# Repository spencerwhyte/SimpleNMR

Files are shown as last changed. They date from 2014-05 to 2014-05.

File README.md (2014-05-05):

Simple NMR
==============
This is my first adventure into NMR and I want to keep everything as simple as possible for the first design. 

The process goes a little something like this.

1. Apply a pre-polarizing pulse to the sample.
2. Transmit 90 degree pulse
3. Listen to the FID

Transmit/Receive Board
----------

There is a board which controls the polarization, transmission amplification, and receiver amplification. kicad designs for this board can be found in the RelayBoard folder.

To elaborate on the simple process described above, here is what actually happens.

1. Apply a pre-polarizing pulse to the sample
	- Configure the relays to disable transmit and receive functionality (To protect the electronics)
	- Turn on the polarization coil
	- Wait some fixed period of time
	- Turn off the polarization coil 

2. Transmit 90 degree pulse
	- Configure the relays to allow transmission
	- Tell GNURadio to output a sine wave at the larmour frequency to the sound card/audio interface
	- Wait 90 degrees worth of time
	- Tell GNURadio to stop the output
	- Configure the relays to disable transmission

3. Listen to the FID
	- Configure the relays to enable receiving
	- Tell GNURadio to record from line-in 
	- Apply a Peak hold FFT to the input signal to see what we received

Amplification Board
------------

There is another board which amplifies the transmitted and received signals. kicad designs for the amplifier board can be found in the AmplifierBoard folder.

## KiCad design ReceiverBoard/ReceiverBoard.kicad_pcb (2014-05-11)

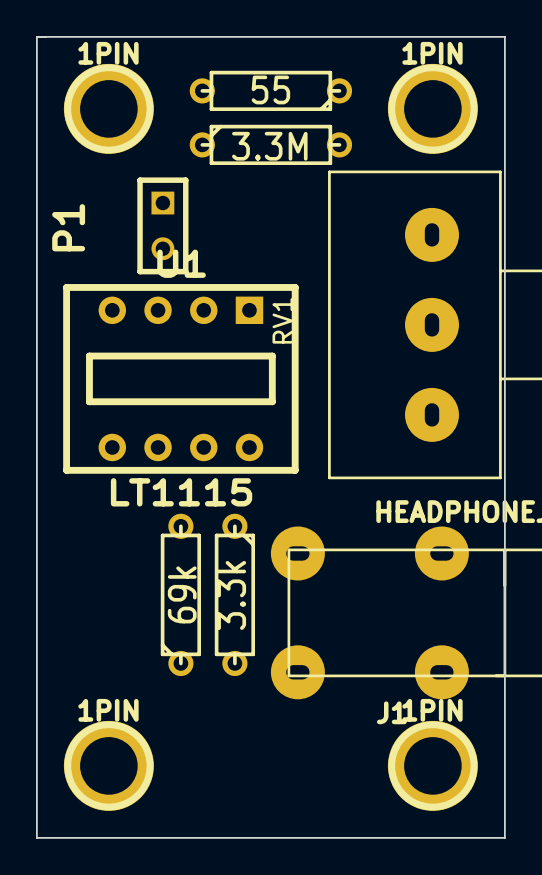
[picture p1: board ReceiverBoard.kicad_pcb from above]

Board: 2 copper layers, 26.0 x 44.5 mm, 12 parts (0 on the bottom side), 6 nets, no tracks yet.

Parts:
1PIN, 1PIN#2, 1PIN#3, 1PIN#4: P***; 1pin
J1: HEADPHONEJACK; HeadphoneJack
P1: CONN_2; PinHeader2
R1: 3.3M; R3
R2: 55; R3
R3: 69k; R3
R4: 3.3k; R3
RV1: POT; POT_P160KN
U1: LT1115; SWDIP4

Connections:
GND: J1.1, P1.1, R2.2, R4.1
unnamed: R1.2, R2.1, RV1.1
unnamed: R3.2, RV1.2, U1.6
unnamed: J1.2, R3.1, R4.2
unnamed: R1.1, U1.2
unnamed: P1.2, U1.3

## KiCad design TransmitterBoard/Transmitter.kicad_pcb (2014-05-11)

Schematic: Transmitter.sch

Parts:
J1: JACK_STEREO
K1: CONN_3
P1: CONN_2
R1: Rin
R2: Rf
RV1: 10k
U1: LF411

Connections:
GND: J1.1, K1.2 (PM), P1.2 (PM), R1.1
unnamed: R1.2, R2.2, U1.2 (-)
unnamed: J1.2, U1.3 (+)
unnamed: P1.1, RV1.2, U1.6
unnamed: R2.1, RV1.1
VCC: K1.1, U1.7 (v+)
VEE: K1.3, U1.4 (V-)

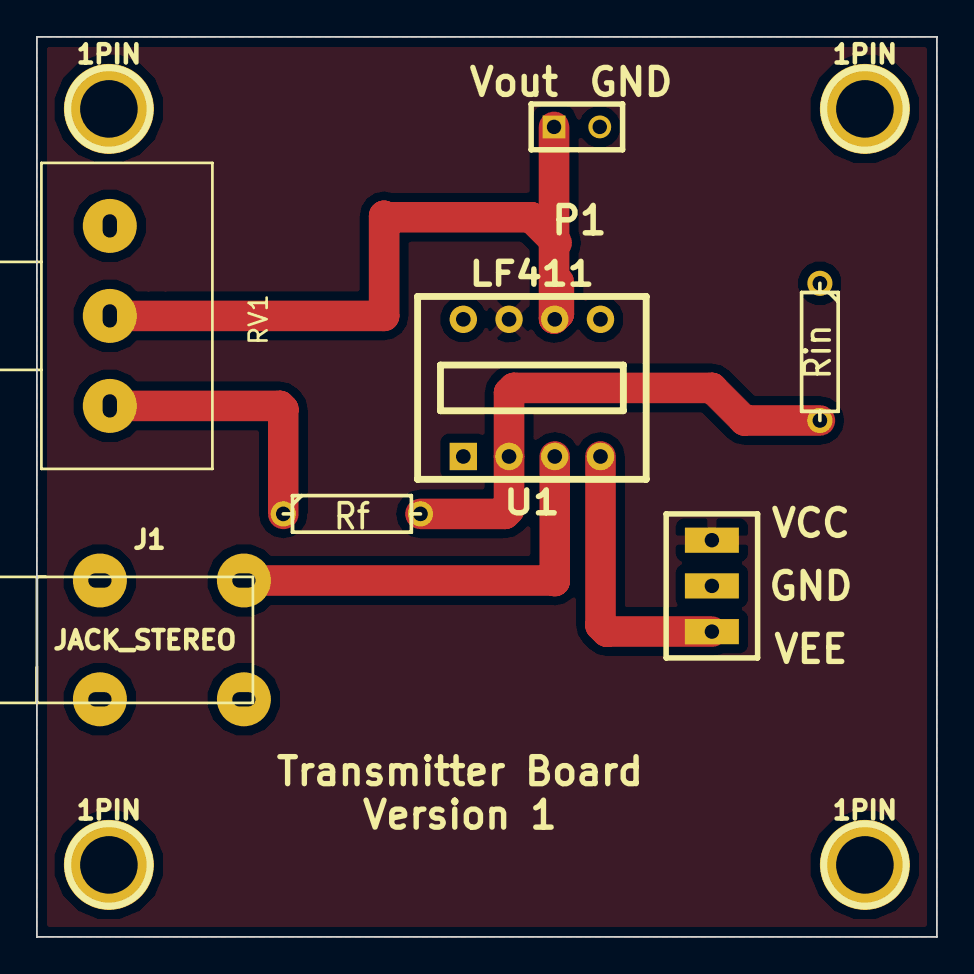
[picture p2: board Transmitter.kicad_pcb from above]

Board: 2 copper layers, 50.0 x 50.0 mm, 11 parts (0 on the bottom side), 7 nets.

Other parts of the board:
1PIN, 1PIN#2, 1PIN#3, 1PIN#4: P***; 1pin

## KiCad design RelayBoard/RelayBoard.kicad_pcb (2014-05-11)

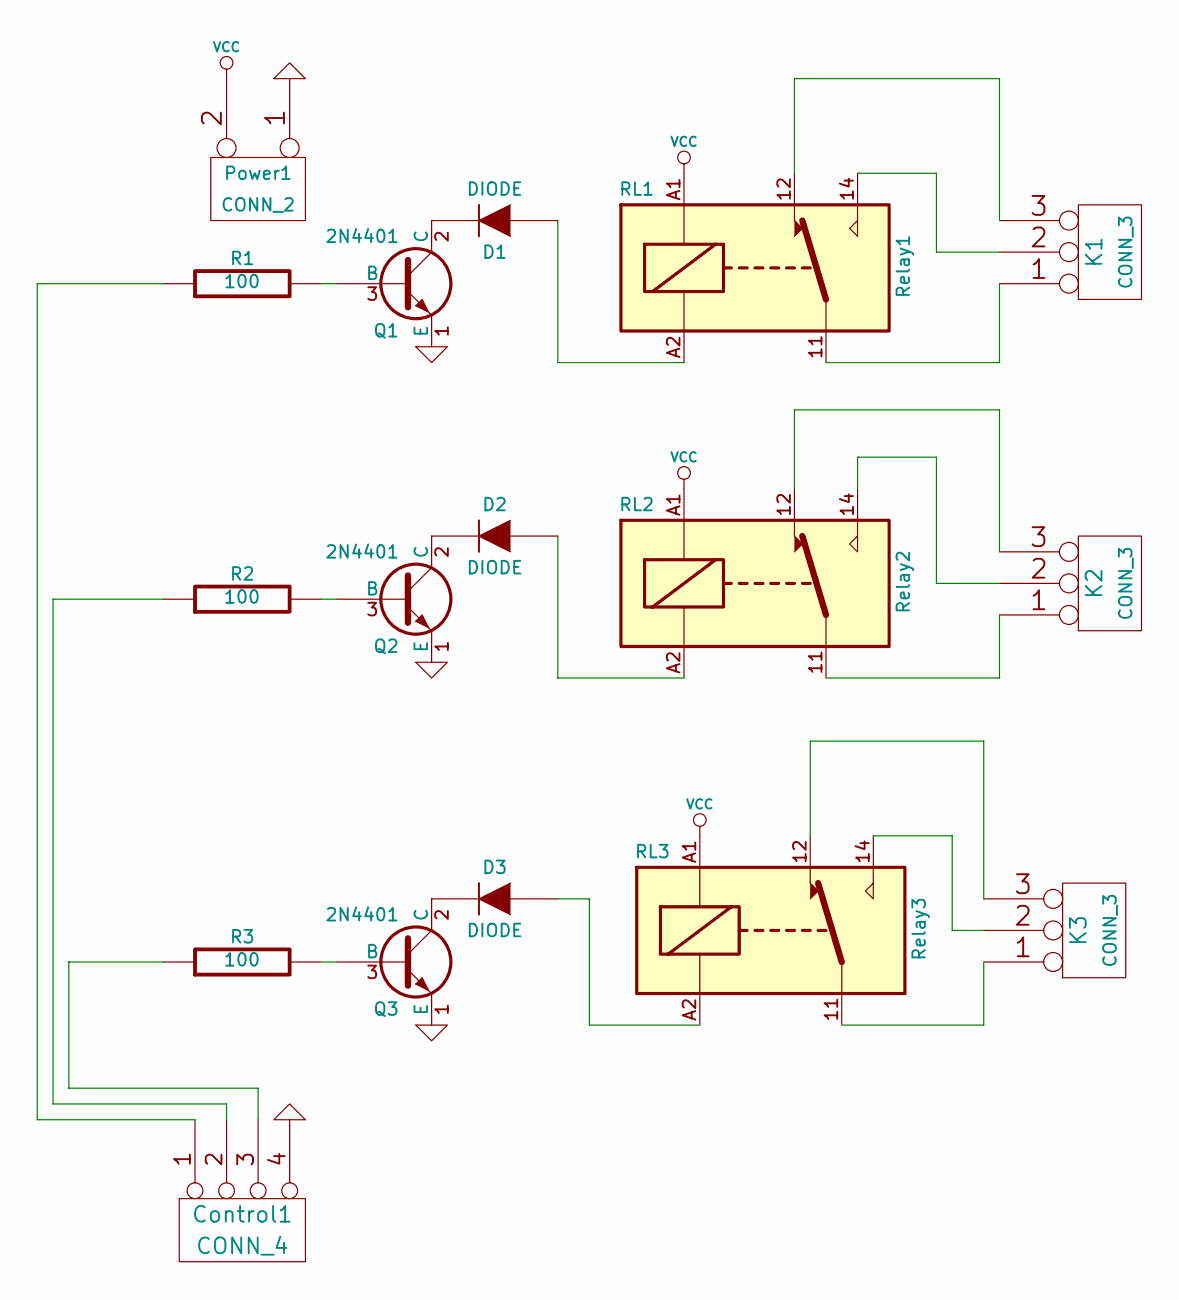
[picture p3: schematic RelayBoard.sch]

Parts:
Control1: CONN_4
D1, D2, D3: DIODE
K1, K2, K3: CONN_3
Power1: CONN_2
Q1, Q2, Q3: 2N4401
R1, R2, R3: 100
RL1: Relay1
RL2: Relay2
RL3: Relay3

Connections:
GND: Control1.4, Power1.1, Q1.1 (E), Q2.1 (E), Q3.1 (E)
unnamed: K2.3, RL2.12
unnamed: K2.1, RL2.11
unnamed: K3.3, RL3.12
unnamed: K3.2 (PM), RL3.14
unnamed: K3.1, RL3.11
unnamed: K2.2 (PM), RL2.14
unnamed: K1.2 (PM), RL1.14
unnamed: K1.3, RL1.12
unnamed: K1.1, RL1.11
unnamed: D3.2 (K), Q3.2 (C)
unnamed: D2.2 (K), Q2.2 (C)
unnamed: D1.2 (K), Q1.2 (C)
unnamed: Q3.3 (B), R3.2
unnamed: Control1.3, R3.1
unnamed: Q2.3 (B), R2.2
unnamed: Q1.3 (B), R1.2
unnamed: Control1.1, R1.1
unnamed: D3.1 (A), RL3.A2
unnamed: D2.1 (A), RL2.A2
unnamed: D1.1 (A), RL1.A2
unnamed: Control1.2, R2.1
VCC: Power1.2 (PM), RL1.A1, RL2.A1, RL3.A1

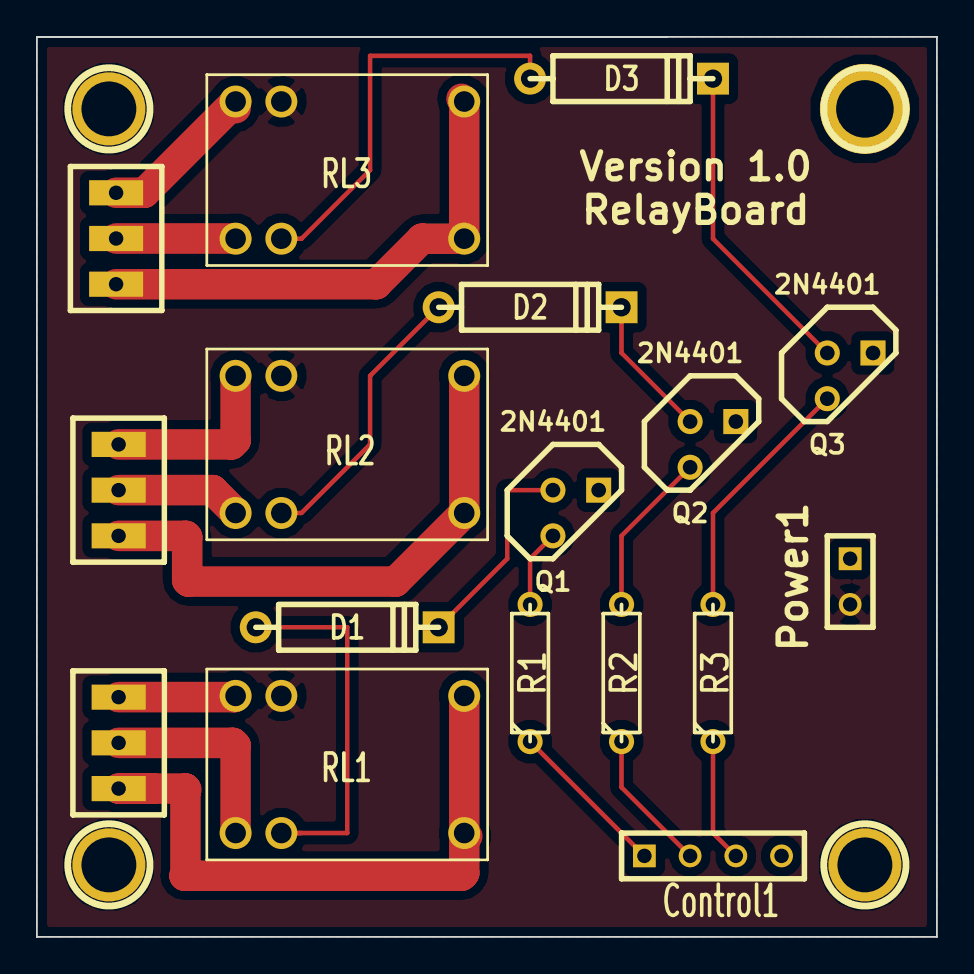
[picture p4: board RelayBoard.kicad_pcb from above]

Board: 2 copper layers, 50.0 x 50.0 mm, 21 parts (0 on the bottom side), 23 nets.

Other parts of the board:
1PIN, 1PIN#2, 1PIN#3, 1PIN#4: P***; 1pin

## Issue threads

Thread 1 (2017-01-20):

Would this work directly with a SDR?

lostinblue, 2017-01-20:
Could I just use this directly with an SDR like hackerRF?

spencerwhyte, 2017-01-31:
The short answer is not easily.

The long answer is, yes, and I want to try it someday! The cutoff frequency of the HackRF is about 10 MHz. Lets say you give yourself 1 MHz of bandwidth (that is an outrageous amount of bandwidth). You would need to get the hydrogen atoms talking at 11 MHz.

The Gyromagnetic ratio of hydrogen is 42.58 Mhz / Tesla.

B = 11 Mhz / (42.58 MHz / Tesla) = 0.25833 Tesla

Therefore you would need to have a homogeneous 0.258 T field on your sample, which isn't easy / cheap (unless you go for a smaller sample size).

kziblk, 2017-02-02:
I have one and I'm trying it now, I'm more of a programmer than a physicist though, I just think this would be awesome to have open source. I actually have two, I was planning on dedicated one to transmission and one to receiving.

If you have time to answer my stupid questions and help me make sense of it I could build on what you have here I would really appreciate it.

I have over 1 T field but I'm having trouble making sense of how exactly I should generate the Lam- frequency and how I should build the receiver coil.

kziblk, 2017-02-02:
Should I just be using RPITX + raspberry pi 3 to do the transmission? Seems like a much cheaper solution.

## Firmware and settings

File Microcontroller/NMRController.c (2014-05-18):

#include <msp430g2553.h>

/*
By: Spencer Whyte

This controls the polarization and transmit/receive coils by listening
for commands over a serial connection and controlling the relays.

This just turns the MSP430 into a cheap serial to parallel converter

*/

void enableUARTInterrupt(){
	IE2 |= UCA0RXIE; // Enable RX interrupt
}

void disableUARTInterrupt(){
	IE2 &= ~UCA0RXIE;
}


// Initializes the hardware used for the serial connection
// 9600 Baud
// 8N1
void initialize_uart(){
	BCSCTL1 = CALBC1_1MHZ; // Set DCO
	DCOCTL = CALDCO_1MHZ;
	P1SEL = BIT1 + BIT2 ; // P1.1 = Polarization, P1.2=T/R
	P1SEL2 = BIT1 + BIT2 ; // P1.1 = Polarization , P1.=T/R
	UCA0CTL1 |= UCSSEL_2; // SMCLK
	UCA0BR0 = 104; // 1MHz 9600
	UCA0BR1 = 0; // 1MHz 9600
	UCA0MCTL = UCBRS0; // Modulation
	UCA0CTL1 &= ~UCSWRST; // Initialize USCI state machine
}

void wait_for_button_press(){
	__bis_SR_register(LPM0_bits + GIE); // Enter low power mode and wait for the user to press the button
		
}

void initialize_leds(){
	P1DIR |= (BIT0|BIT4|BIT5); // Set the LEDs on P1.0, P1.6 as outputs
	P1OUT = 0; // Indicate that serial transfer is incomplete by displaying the yellow light
}

void main(void)
 
{
	WDTCTL = WDTPW + WDTHOLD; // Stop WDT

	initialize_leds(); // Initialize the LED's

	initialize_uart(); // Initialize the hardware for the serial connection
	
	enableUARTInterrupt();	

	__bis_SR_register(LPM0_bits + GIE); // Enter low power mode and wait for serial transfer to complete

	while(1){

	}
}




// Interrupt for the REPLAY button press
__attribute__((interrupt(PORT1_VECTOR)))
void Port_1_ISR(void)
{
	P1IFG &= ~0x08; // P1.3 IFG cleared
	__bic_SR_register_on_exit(CPUOFF);
}

 
// Echo back RXed character, confirm TX buffer is ready first

__attribute__((interrupt(USCIAB0RX_VECTOR)))
void USCI0RX_ISR(void){
		
	/*
		BEGIN JUNK
		This is only going to slow things down if we send the character back
	*/
	while (!(IFG2&UCA0TXIFG)); // USCI_A0 TX buffer ready?
	UCA0TXBUF = UCA0RXBUF; // Echo back received character
	/*
		END JUNK
	*/
	
	if((UCA0RXBUF & 1) != 0){ // Pin 1.0
		P1OUT |= BIT0;
	}else{
		P1OUT &= ~BIT0;
	}

	if((UCA0RXBUF & 2) != 0){ // Pin 1.4 
                P1OUT |= BIT4;
        }else{
                P1OUT &= ~BIT4;
        }

	if((UCA0RXBUF & 4) != 0){ // Pin 1.5 
                P1OUT |= BIT5;
        }else{
                P1OUT &= ~BIT5;
        }

}

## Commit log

2014-04-19 Began testing of relay switching speed
2014-05-05 Added kicad board design
    [RelayBoard.kicad_pcb, RelayBoard.sch]
2014-05-05 Completed RelayBoard PCB Design
    [RelayBoard.kicad_pcb, RelayBoard.sch]
2014-05-06 Fixed pin header spacing on all connectors
    [RelayBoard.kicad_pcb]
2014-05-11 Added transmitter amplifier board and the corresponding gerbers
    [RelayBoard.kicad_pcb]
2014-05-11 Completed receiver schematic+footprints+90% of the PCB
    [.kicad_pcb.kicad_pcb, ReceiverBoard.kicad_pcb, ReceiverBoard.sch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]
